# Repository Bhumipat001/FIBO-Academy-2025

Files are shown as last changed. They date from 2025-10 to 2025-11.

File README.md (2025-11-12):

# The Desktop Friend Robot (Companion Robot)

## Project CatLover
A robotic friend that follows and interacts with humans, designed with a cute and emotional personality.

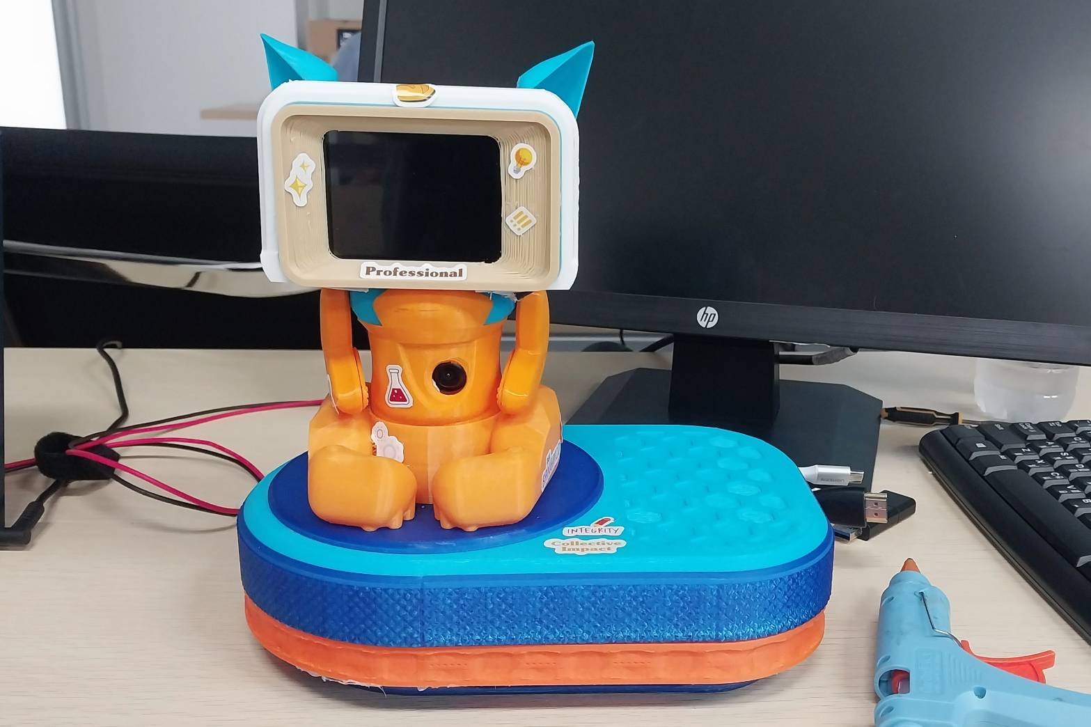
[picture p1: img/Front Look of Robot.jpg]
Front View of the Robot


This project is currently a prototype that simulates some of the features envisioned for the robot.

---

## What Does the Program Do?
The program is designed to **sense humans and interact with them based on specific conditions**.

### Devices Used
The project involves two main devices:
1. **ESP32 (WROOM)** - Handles low-level support and acts as a hub for sensors.
2. **Raspberry Pi (4 Model B)** - Provides high-level support for advanced features.

### ESP32 Features
- **Sensors**:
  - Capacitive Touch (built-in)
  - 24GHz mmWave Radar (via UART - Serial2)
- **Actuators**:
  - Vibrator Motor (PWM)
  - Light Strip (WS2812B)
  - Servo Motors

### Raspberry Pi Features
- **Image Processing**: Object detection
- **Display**: ILI9341V (via SPI)
- **Sound**: Audio output
- **Motion Expression**

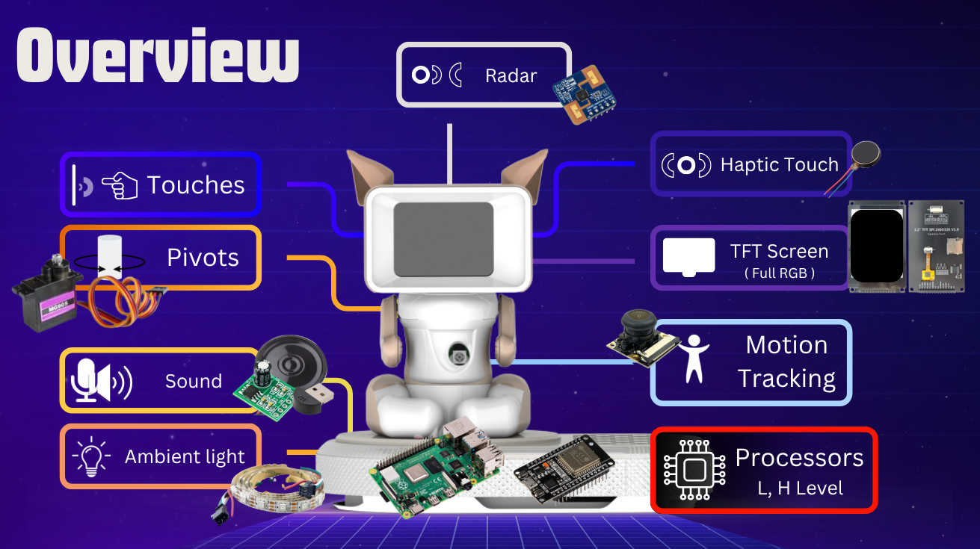
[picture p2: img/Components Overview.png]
Components of the Robot


---

## Components

### ESP32 Connections
| Device | Connection |
|---|---|
| Servo | PWM: 4, 5, 16, 17, 18, 19, 21, 22 |
| Touch (Wire/Metal Sheet)| GPIO: 12, 13, 14, 27, 32, 33 |
| Light Strip | NZR: 0, 23 |
| Radar | UART: Serial2 |
| Vibrator (Signal) | PWM: 2 |
| Raspberry Pi | UART: Serial0 |

### Raspberry Pi Connections
| Device | Connection |
|---|---|
| Pi Camera | SCI (Ribbon Cable) |
| Display | SPI: 8(CS), 9(MISO), 10(MOSI), 11(SCK), 24(RS), 25(RST) |
| ESP32 | UART: Serial |
| Speaker | Aux Jack |

---

## Design
The robot is designed to **mimic a cat-like appearance** with creative elements, including a CRT display head and a hybrid human-like look.

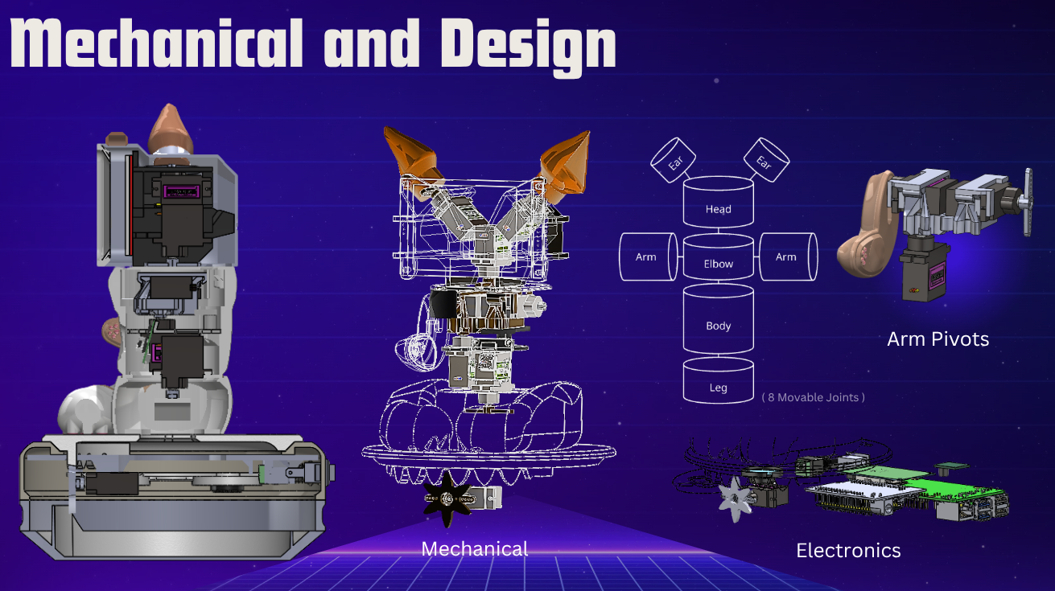
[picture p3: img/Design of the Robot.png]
Design of the Robot


### 3D Design (CAD)
- [STEP Assembly](https://github.com/Bhumipat001/FIBO-Academy-2025/tree/main/CAD/STEP)
- [STL Files](https://github.com/Bhumipat001/FIBO-Academy-2025/tree/main/CAD/STL)

**Note**: The design is optimized for **3D printing** (FDM printers).

---

## Materials
### Sensors
- `1` 24GHz mmWave Radar (Waveshare)
- `1` Pi Camera with Fish Eye Lens (130°)
- `A small amount` of thin metallic material (e.g., aluminum tape)

### Actuators
- `8` Servo Motors
- `2` Light Strips (WS2812B)
- `1` Vibrator Motor

### Compute Modules
- `1` ESP32 WROOM
- `1` Raspberry Pi 4 Model B

### Other Components
- `1` 3.2" TFT Screen
- `1` Speaker (10 mm or 17 mm) with Amplifier
- `Some` wires, power supply, switches, connectors, etc.

---

## Program Summary
The system uses a local **MQTT broker** (e.g., Mosquitto) for communication between the Raspberry Pi and ESP32 (via a middleware program).

### Simplified Algorithms
#### Raspberry Pi
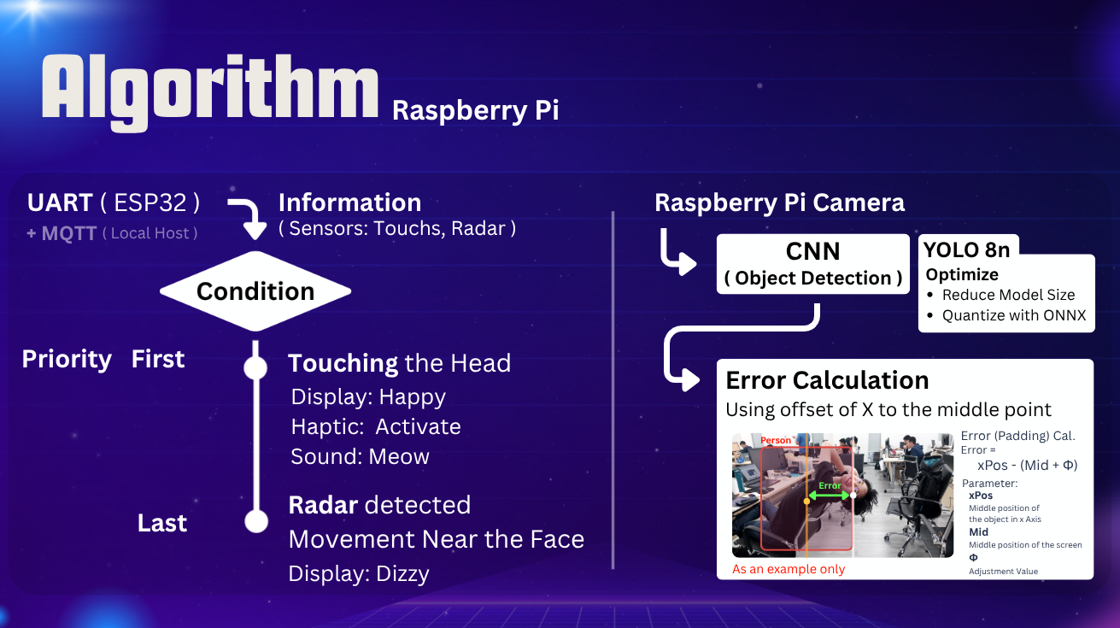
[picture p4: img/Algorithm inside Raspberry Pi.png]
Simplified Algorithm of Raspberry Pi


#### ESP32
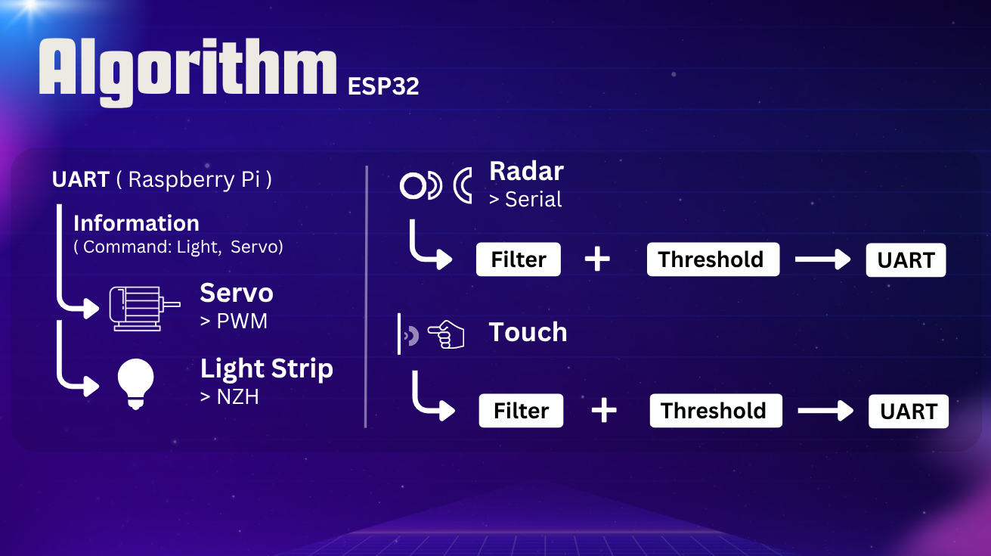
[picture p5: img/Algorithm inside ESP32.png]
Simplified Algorithm of ESP32


---

### Tracking Program
The repository includes an object detection model optimized from YOLOv8n. The program's goal is to move the focus object to the center of the screen.

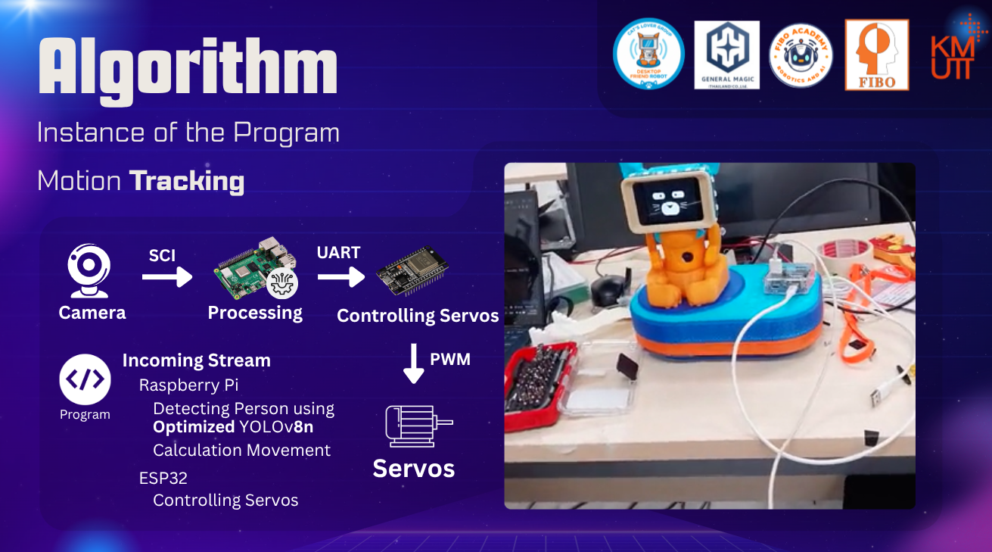
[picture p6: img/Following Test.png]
Algorithm of the Tracking Program


---

### Radar Program
This implementation tests the radar's ability to sense a hand in front of the robot's face without physical contact. The radar uses the Doppler effect to detect motion.

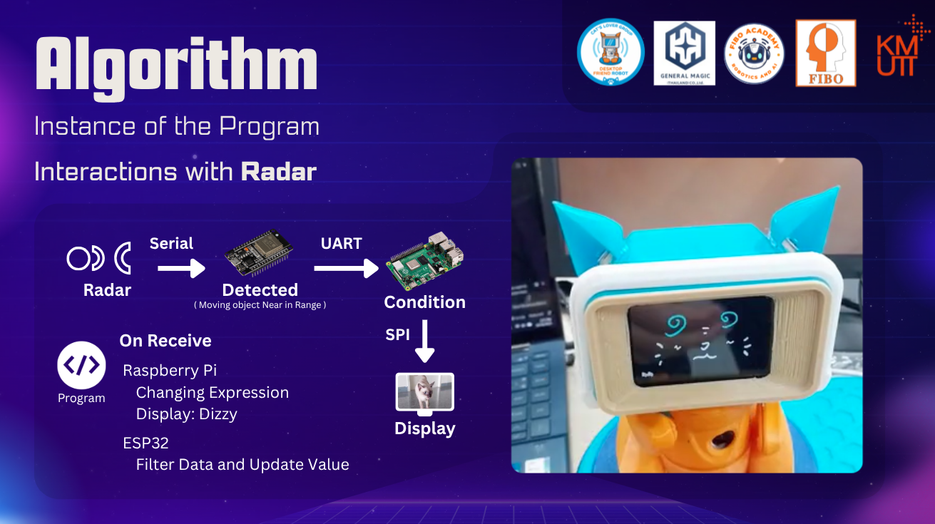
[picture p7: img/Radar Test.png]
Algorithm of the Radar Program


**Note**: 
- The algorithm can be improved in many ways.
- The radar is more effective at detecting moving objects but may produce noise if the sensor itself moves.

For more details, refer to the [presentation slides](https://github.com/Bhumipat001/FIBO-Academy-2025/blob/main/Present%20Slide.pdf).

---
## Setup
Follow these steps to set up the system. Note that this is a basic setup and may require adjustments.

### Raspberry Pi Setup
**Distro**: Raspberry Pi OS (default username: `pi`)

1. **Update and Install Dependencies**  
   - Update the system and install required libraries.  
   - Enable SPI and UART pins via `raspi-config`.

2. **Create a Python Virtual Environment**  
   ```bash
   cd ~
   python3 -m venv RobotEnv
   ```

3. **Install Python Libraries**  
   Activate the virtual environment and install the required libraries.

4. **Clone the Raspberry Pi Code**  
   ```bash
   cd ~
   git clone https://github.com/Bhumipat001/FIBO-Academy-2025.git
   mv FIBO-Academy-2025/Desktop\ Friend\ Robot/Raspberry\ Pi\ 4/ ~/RobotFriend
   rm -rf ~/FIBO-Academy-2025
   ```

5. **Create and Enable a Systemd Service Unit File**  
   Set up a service to run the program automatically on boot.

6. **Test and Run the Program**  
   Start the program and ensure everything is working as expected.

---

### ESP32 Setup
1. **Install Required Libraries**  
   Install the necessary libraries in your Arduino IDE or other development environment.

2. **Upload the Code**  
   Flash the ESP32 with the provided code.

3. **Test the Setup**  
   Verify the ESP32 is communicating correctly with the Raspberry Pi.

---

**Note**: For both setups, patience and testing are key. Good luck! Gooses and Cats bless you🙏

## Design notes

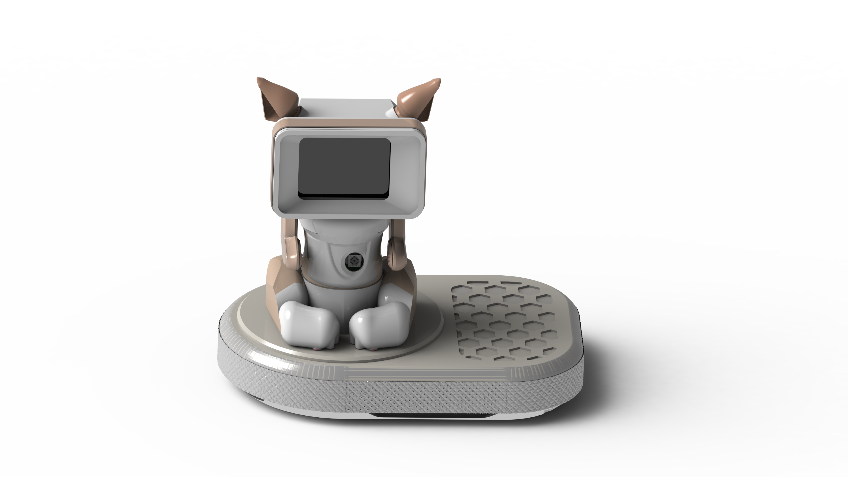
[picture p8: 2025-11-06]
CAD/Render/Assem TF View.png

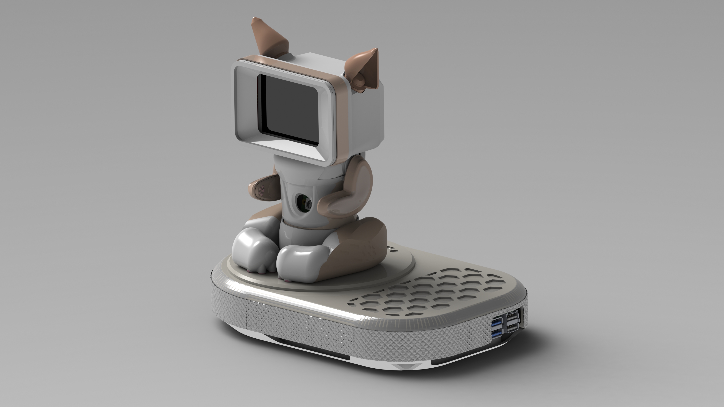
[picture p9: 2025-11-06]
CAD/Render/Assem RF View.JPG

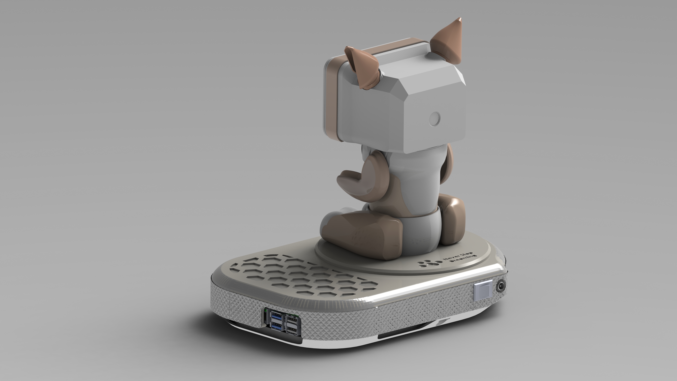
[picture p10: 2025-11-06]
CAD/Render/Assem RB View.JPG

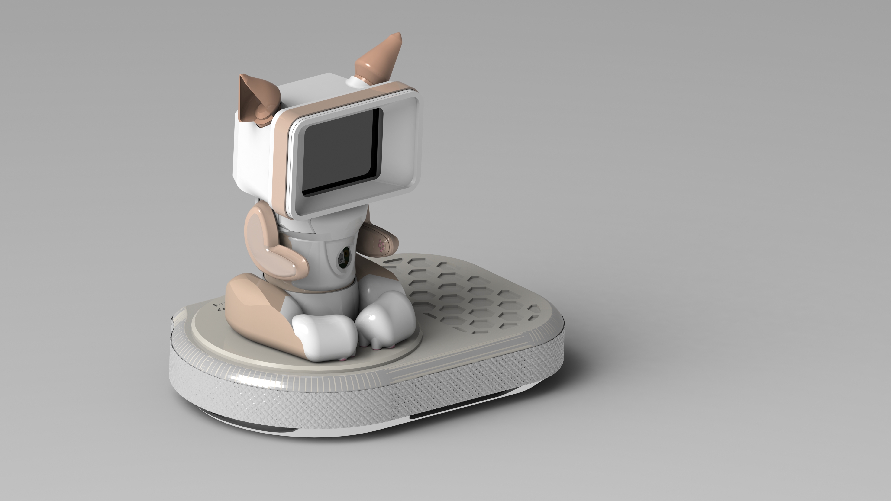
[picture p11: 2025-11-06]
CAD/Render/Assem ISO View.JPG

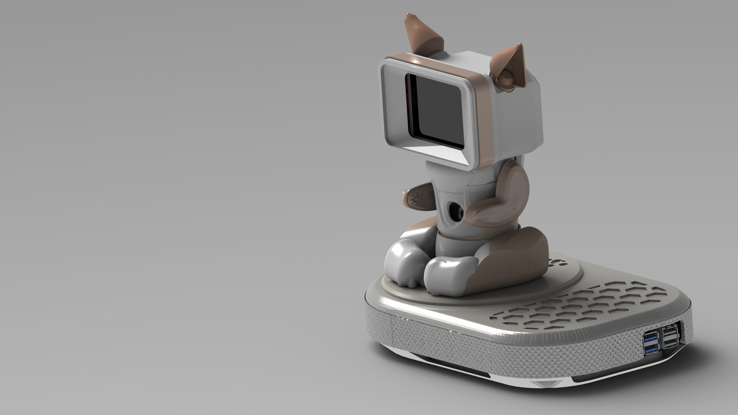
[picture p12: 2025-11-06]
CAD/Render/Assem RrF View.JPG

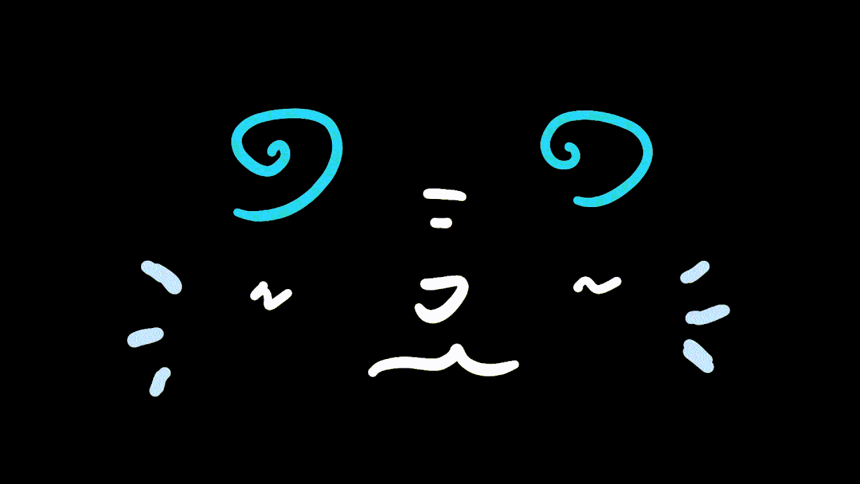
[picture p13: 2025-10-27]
Desktop Friend Robot/Raspberry Pi 4/screen/dizzy.gif

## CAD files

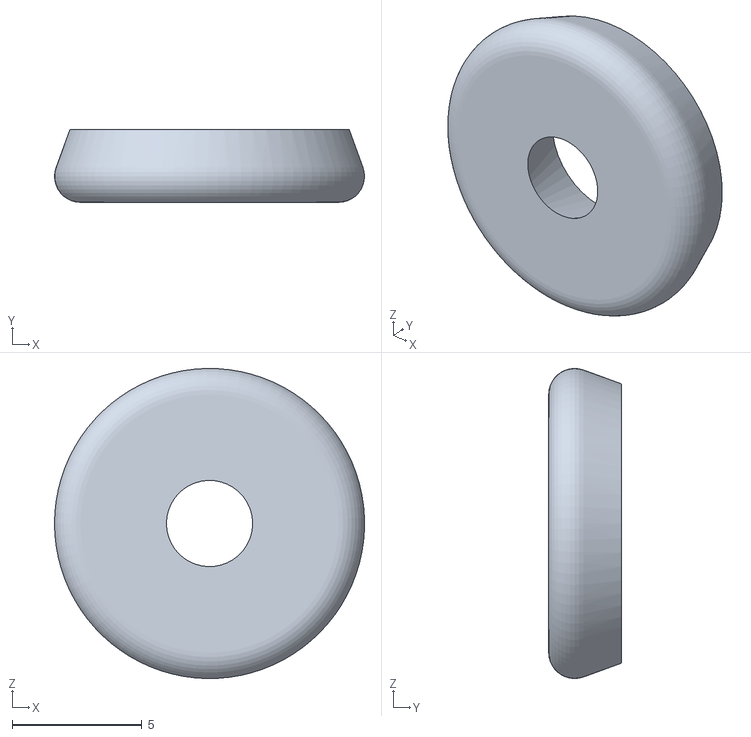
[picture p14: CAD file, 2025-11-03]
CAD/STL/Base and Leg/Base Connector Ring x2.STL
11.9 x 2.80 x 11.9

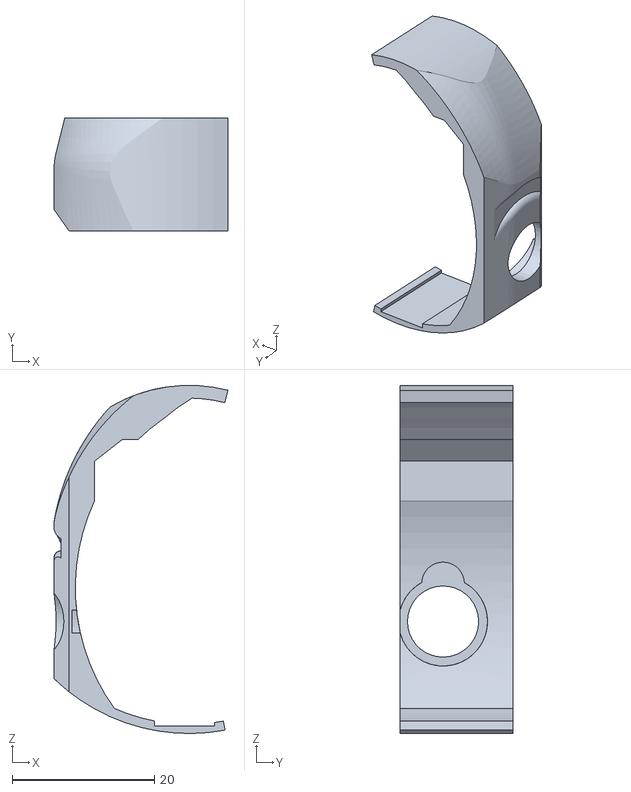
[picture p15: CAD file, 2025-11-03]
CAD/STL/Body/Body Right Cover.STL
24.5 x 15.8 x 48.9

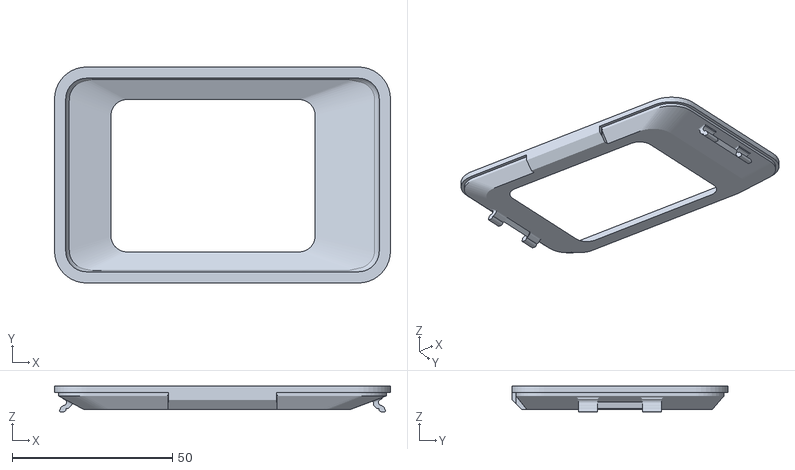
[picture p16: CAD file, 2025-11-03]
CAD/STL/Head/Head Front Cover.STL
105.0 x 67.5 x 8.00

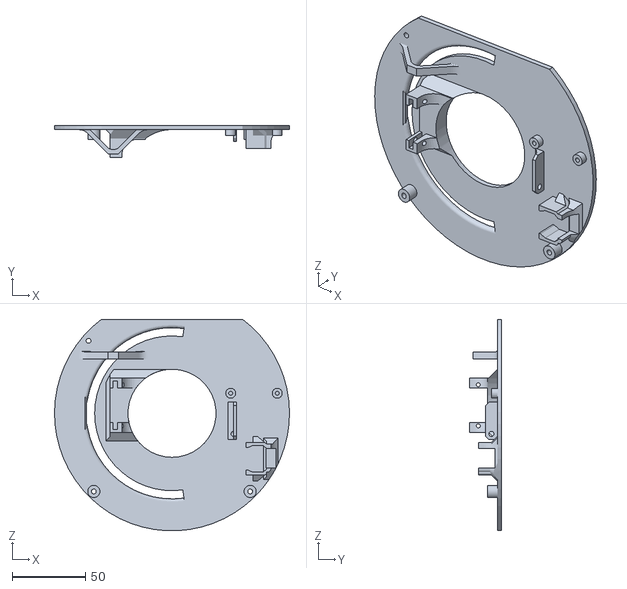
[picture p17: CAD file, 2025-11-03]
CAD/STL/Base and Leg/Base L1.STL
160.1 x 22.1 x 143.9

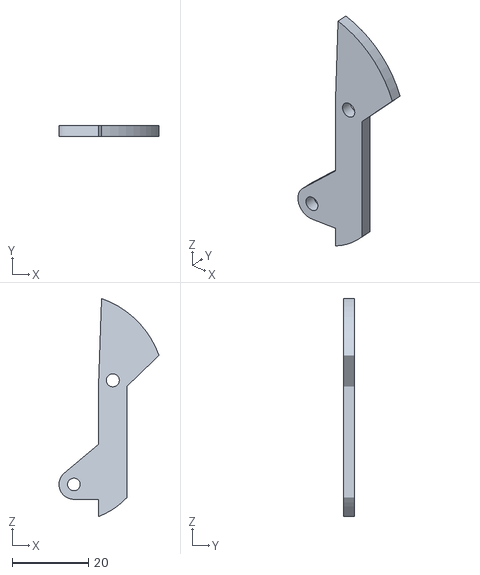
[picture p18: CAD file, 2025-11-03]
CAD/STL/Body/Body L2.STL
26.2 x 2.80 x 57.1

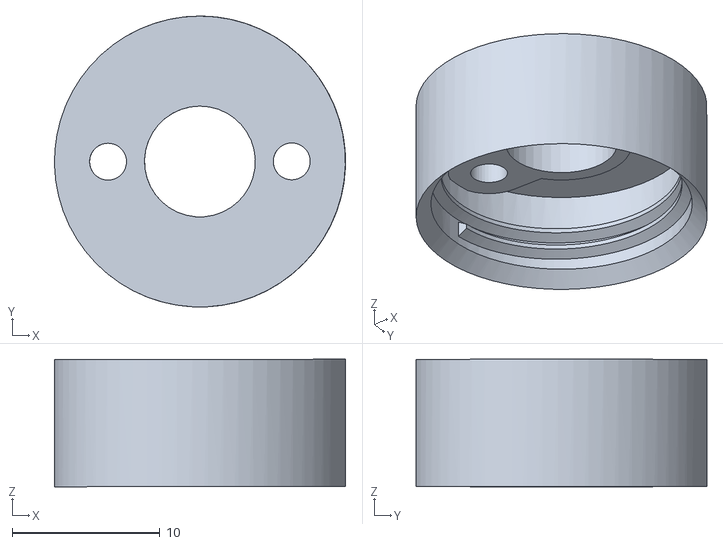
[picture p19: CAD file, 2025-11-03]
CAD/STL/Head/Servo Ear Right Connector.STL
19.7 x 19.7 x 8.63

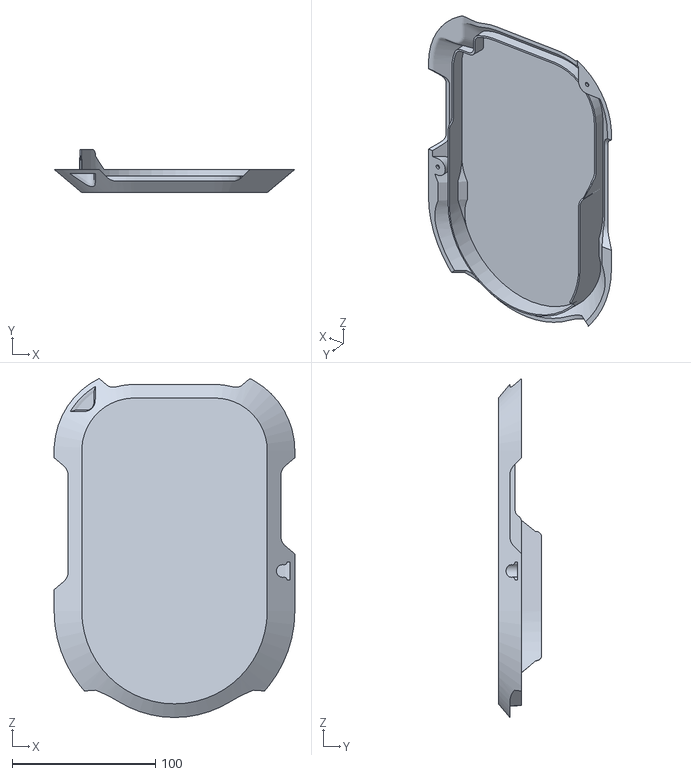
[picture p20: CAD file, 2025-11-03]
CAD/STL/Base and Leg/Base Cover.STL
168.0 x 30.2 x 236.5

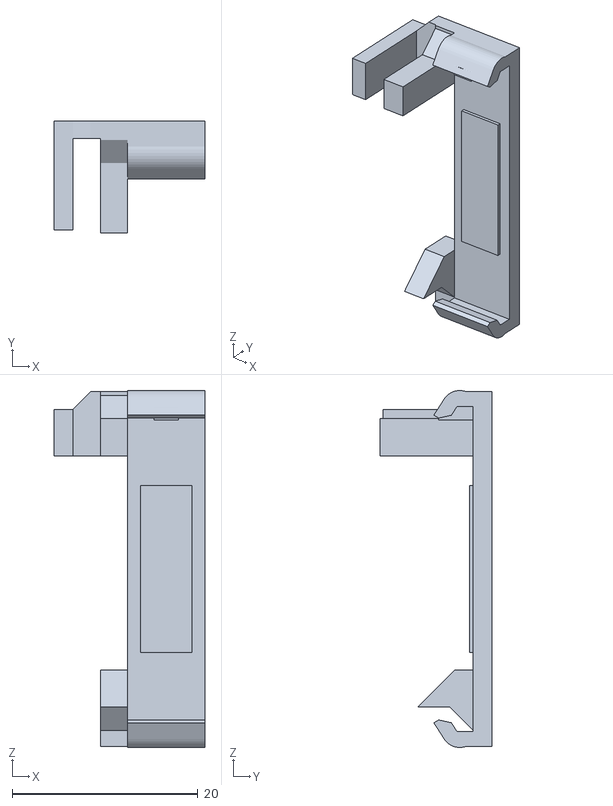
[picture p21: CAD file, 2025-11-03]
CAD/STL/Body/Gear Locker Right.STL
16.2 x 12.0 x 38.4

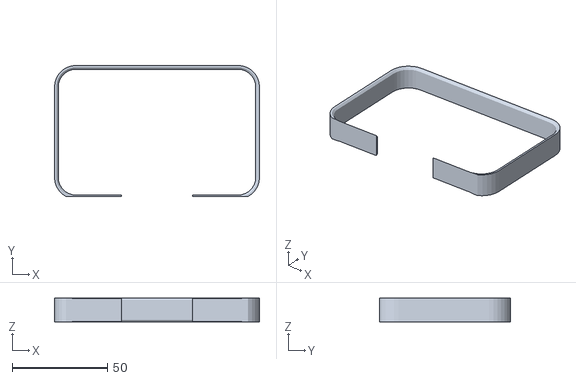
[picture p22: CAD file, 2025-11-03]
CAD/STL/Head/Head noDiff.STL
107.5 x 68.8 x 12.4

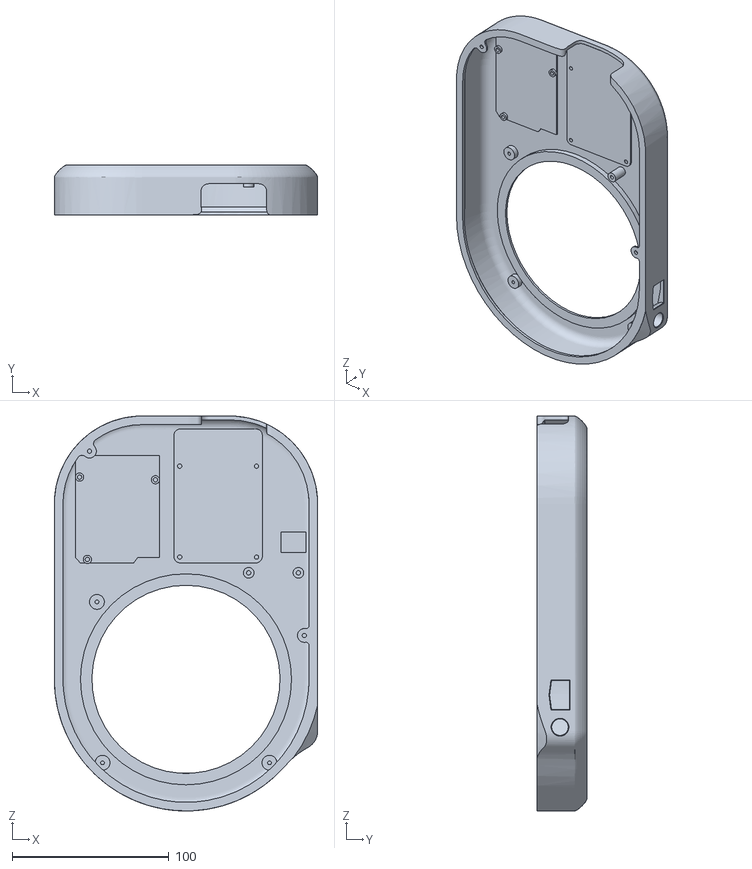
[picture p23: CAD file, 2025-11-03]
CAD/STL/Base and Leg/Base.STL
168.0 x 32.0 x 252.0

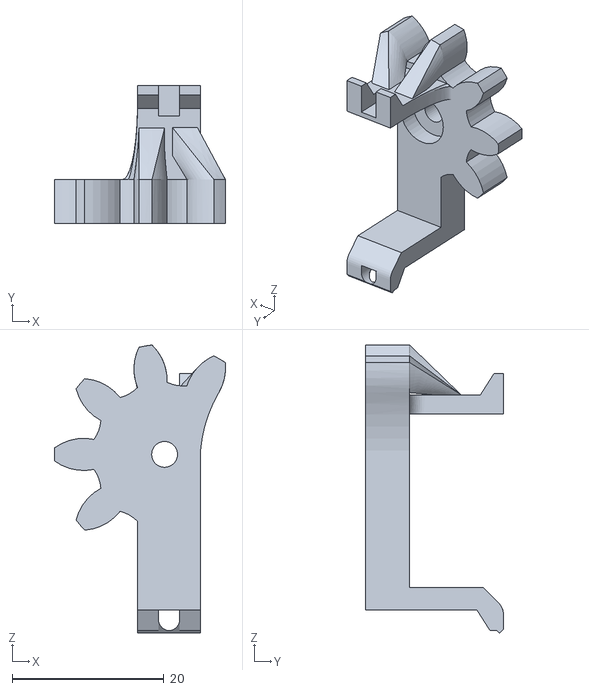
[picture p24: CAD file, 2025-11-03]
CAD/STL/Body/Gear Left.STL
22.5 x 18.2 x 37.9

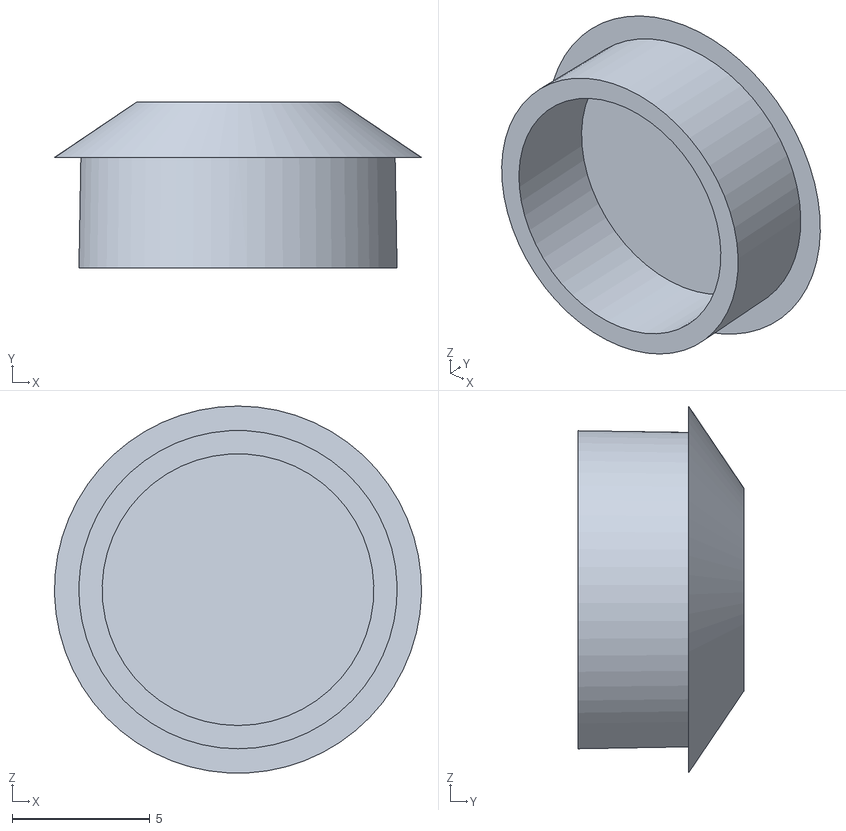
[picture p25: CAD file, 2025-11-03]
CAD/STL/Head/Servo Ears Cover x2.STL
13.3 x 6.00 x 13.3

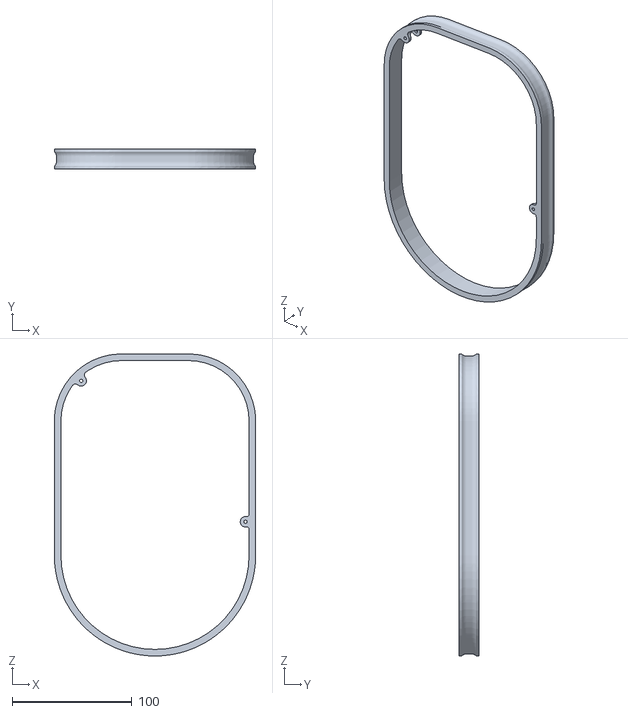
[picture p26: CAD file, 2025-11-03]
CAD/STL/Base and Leg/Base Extender.STL
168.0 x 17.0 x 252.0

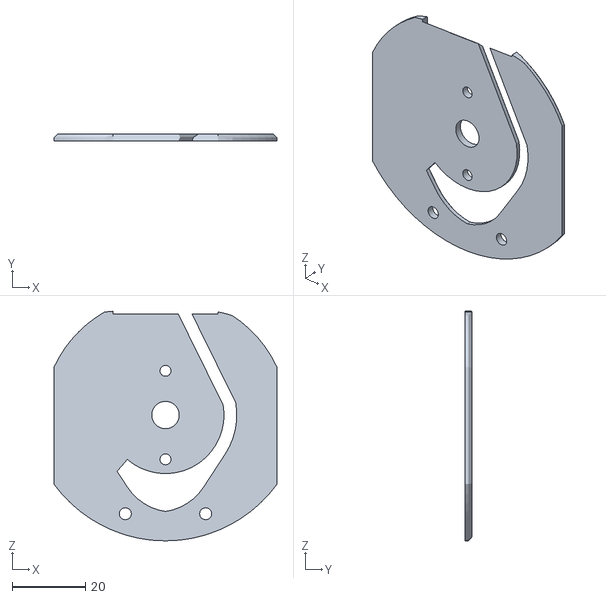
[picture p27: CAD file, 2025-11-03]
CAD/STL/Body/Body L3.STL
61.0 x 1.90 x 62.8

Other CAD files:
CAD/STL/Head/Head Diff.STL
CAD/STL/Base and Leg/Speaker Holder.STL
CAD/STL/Body/Body Left Cover.STL
CAD/STL/Head/Servo Ear Left Connector.STL
CAD/STL/Base and Leg/Base Connector Gear.STL
CAD/STL/Base and Leg/Base Connector.STL
CAD/STL/Base and Leg/Leg.STL
CAD/STL/Body/Body L1.STL
CAD/STL/Body/Body.STL
CAD/STL/Body/Gear Locker Left.STL
CAD/STL/Body/Gear Right.STL
CAD/STL/Head/Head Shell.STL
CAD/STL/Head/Head Structure.STL
CAD/STL/Head/Left Ear.STL
CAD/STL/Head/Right Ear.STL

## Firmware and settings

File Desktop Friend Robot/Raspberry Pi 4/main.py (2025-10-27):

import threading
import time
import paho.mqtt.client as mqtt

MQTT_BROKER = "localhost"
MQTT_PORT = 1883

TOPIC_TOUCH = "/touch"
TOPIC_HAPTIC = "/haptic"
TOPIC_SERVO = "/servo"
TOPIC_SCREEN = "/screen"
TOPIC_RADAR = "/radar"
TOPIC_SOUND = "/sound"
TOPIC_SLEEP = "/sleep"

class HeadState:
    def __init__(self):
        self.lock = threading.Lock()
        self.head_active_now = False
        self.active = False
        self.off_timer = None
        self.radar_active = False
        self.radar_off_timer = None
        self.radar_blocked = False
        self.radar_block_timer = None
        self.sleeping = False
        self.inactivity_timer = None
        self.radar_subscribed = True

def parse_touch_payload(payload: str):
    try:
        s = payload.strip()
        if s.lower().startswith("touch:"):
            s = s.split(":", 1)[1].strip()
        parts = [p.strip() for p in s.split(",") if p.strip()]
        result = {}
        for part in parts:
            if "=" in part:
                k, v = part.split("=", 1)
                result[k.strip()] = int(v.strip())
        return result
    except Exception:
        return {}

def on_connect(client, userdata, flags, reasonCode, properties=None):
    try:
        code = int(reasonCode)
    except Exception:
        code = reasonCode
    print(f"Connected to MQTT broker with result code: {code}")
    client.subscribe(TOPIC_TOUCH)
    print(f"Subscribed to topic: {TOPIC_TOUCH}")
    client.subscribe(TOPIC_SLEEP)
    print(f"Subscribed to topic: {TOPIC_SLEEP}")
    client.subscribe(TOPIC_RADAR)
    print(f"Subscribed to topic: {TOPIC_RADAR}")
    userdata.radar_subscribed = True

def on_message(client, userdata: HeadState, msg):
    if msg.topic == TOPIC_TOUCH:
        handle_touch(client, userdata, msg)
    elif msg.topic == TOPIC_RADAR:
        handle_radar(client, userdata, msg)
    elif msg.topic == TOPIC_SLEEP:
        handle_sleep(client, userdata, msg)

def wake_if_sleeping(client, st: HeadState):
    if st.sleeping:
        client.publish(TOPIC_SLEEP, "0")
        print("Waking from sleep -> sleep=0")
        st.sleeping = False
        if not st.radar_subscribed:
            client.subscribe(TOPIC_RADAR)
            st.radar_subscribed = True
            print(f"Subscribed to topic: {TOPIC_RADAR}")

def update_inactivity_timer(client, st: HeadState):
    idle = not st.head_active_now
    if idle:
        if st.inactivity_timer is None:
            def go_sleep():
                with st.lock:
                    if (not st.head_active_now) and (not st.sleeping):
                        client.publish(TOPIC_SLEEP, "1")
                        print("Inactivity 3m -> sleep=1")
                        st.sleeping = True
                        if st.radar_subscribed:
                            client.unsubscribe(TOPIC_RADAR)
                            st.radar_subscribed = False
                            print(f"Unsubscribed from topic: {TOPIC_RADAR}")
                    st.inactivity_timer = None
            st.inactivity_timer = threading.Timer(180.0, go_sleep)
            st.inactivity_timer.daemon = True
            st.inactivity_timer.start()
    else:
        if st.inactivity_timer:
            st.inactivity_timer.cancel()
            st.inactivity_timer = None

def handle_sleep(client, userdata: HeadState, msg):
    payload = msg.payload.decode("utf-8", errors="ignore").strip().lower()
    try:
        if payload.startswith("sleep:"):
            val = payload.split(":", 1)[1].strip()
        else:
            val = payload
        new_state = (val == "1")
    except Exception:
        return

    st = userdata
    with st.lock:
        prev = st.sleeping
        st.sleeping = new_state
        if new_state:
            if st.inactivity_timer:
                st.inactivity_timer.cancel()
                st.inactivity_timer = None
            if st.radar_subscribed:
                client.unsubscribe(TOPIC_RADAR)
                st.radar_subscribed = False
                print(f"Unsubscribed from topic: {TOPIC_RADAR}")
        else:
            if not st.radar_subscribed:
                client.subscribe(TOPIC_RADAR)
                st.radar_subscribed = True
                print(f"Subscribed to topic: {TOPIC_RADAR}")
            update_inactivity_timer(client, st)
        if new_state != prev:
            print(f"/sleep received -> sleeping={st.sleeping}")

def handle_touch(client, userdata: HeadState, msg):
    payload = msg.payload.decode("utf-8", errors="ignore").strip()
    values = parse_touch_payload(payload)
    L_HEAD = int(values.get("L_HEAD", 0))
    R_HEAD = int(values.get("R_HEAD", 0))
    head_now = (L_HEAD == 1) or (R_HEAD == 1)

    st = userdata
    with st.lock:
        st.head_active_now = head_now

        if head_now:
            wake_if_sleeping(client, st)

            if st.off_timer:
                st.off_timer.cancel()
                st.off_timer = None

            if not st.active:
                client.publish(TOPIC_HAPTIC, "1")
                client.publish(TOPIC_SERVO, "ear1")
                client.publish(TOPIC_SCREEN, "happy")
                client.publish(TOPIC_SOUND, "meow")
                st.active = True
                print("Head touch detected -> haptic=1, servo='ear1', screen='happy', sound='meow'")
            elif st.radar_active:
                client.publish(TOPIC_SCREEN, "happy")
                print("Touch overrides radar -> screen='happy'")
        else:
            if st.off_timer:
                st.off_timer.cancel()

            def do_off():
                with st.lock:
                    if not st.head_active_now and st.active:
                        client.publish(TOPIC_HAPTIC, "0")
                        client.publish(TOPIC_SERVO, "ear0")
                        client.publish(TOPIC_SCREEN, "normal")
                        print("Head released 3s -> haptic=0, servo='ear0', screen='normal'")
                        st.active = False
                        
                        st.radar_blocked = True
                        if st.radar_block_timer:
                            st.radar_block_timer.cancel()
                        
                        def unblock_radar():
                            with st.lock:
                                st.radar_blocked = False
                                st.radar_block_timer = None
                                if st.radar_active and not st.active:
                                    client.publish(TOPIC_SCREEN, "dizzy")
                                    print("Radar unblocked and still active -> screen='dizzy'")
                                else:
                                    print("Radar unblocked after touch cooldown")
                        
                        st.radar_block_timer = threading.Timer(3.0, unblock_radar)
                        st.radar_block_timer.daemon = True
                        st.radar_block_timer.start()
                    st.off_timer = None

            st.off_timer = threading.Timer(3.0, do_off)
            st.off_timer.daemon = True
            st.off_timer.start()

        update_inactivity_timer(client, st)

def handle_radar(client, userdata: HeadState, msg):
    payload = msg.payload.decode("utf-8", errors="ignore").strip()
    
    radar_state = 0
    try:
        if payload.lower().startswith("radar:"):
            radar_state = int(payload.split(":", 1)[1].strip())
        else:
            radar_state = int(payload)
    except Exception:
        return

    st = userdata
    with st.lock:
        if radar_state == 1:
            wake_if_sleeping(client, st)

            if st.radar_off_timer:
                st.radar_off_timer.cancel()
                st.radar_off_timer = None

            if not st.radar_active:
                st.radar_active = True
                if not st.active and not st.radar_blocked:
                    client.publish(TOPIC_SCREEN, "dizzy")
                    print("Radar detected -> screen='dizzy'")
                elif st.radar_blocked:
                    print("Radar detected but blocked (touch cooldown) -> no action")
                else:
                    print("Radar detected but touch active -> keeping screen='happy'")
        else:
            if st.radar_off_timer:
                st.radar_off_timer.cancel()

            def do_radar_off():
                with st.lock:
                    if st.radar_active:
                        st.radar_active = False
                        if not st.active:
                            client.publish(TOPIC_SCREEN, "normal")
                            print("Radar cleared 3s -> screen='normal'")
                        else:
                            print("Radar cleared but touch active -> keeping screen='happy'")
                    st.radar_off_timer = None

            st.radar_off_timer = threading.Timer(3.0, do_radar_off)
            st.radar_off_timer.daemon = True
            st.radar_off_timer.start()

def main():
    state = HeadState()

    client = mqtt.Client(
        protocol=mqtt.MQTTv5,
        callback_api_version=mqtt.CallbackAPIVersion.VERSION2,
        userdata=state,
    )
    client.on_connect = on_connect
    client.on_message = on_message

    client.connect(MQTT_BROKER, MQTT_PORT)
    client.loop_start()

    try:
        while True:
            time.sleep(1)
    except KeyboardInterrupt:
        pass
    finally:
        with state.lock:
            if state.off_timer:
                state.off_timer.cancel()
                state.off_timer = None
            if state.radar_off_timer:
                state.radar_off_timer.cancel()
                state.radar_off_timer = None
            if state.radar_block_timer:
                state.radar_block_timer.cancel()
                state.radar_block_timer = None
            if state.inactivity_timer:
                state.inactivity_timer.cancel()
                state.inactivity_timer = None
        client.loop_stop()
        client.disconnect()

if __name__ == "__main__":
    main()

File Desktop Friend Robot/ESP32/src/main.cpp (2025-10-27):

#include <Arduino.h>
#include <ESP32Servo.h>
#include <Adafruit_NeoPixel.h>
#include "servo.h"
#include "light.h"
#include "touch.h"
#include "radar.h"
#include "follow.h"
#include "haptic.h"

const unsigned long LOOP_MS = 25;
const int BOOT_PIN = 15;
unsigned long lastCheckTime = 0;
bool bootSequenceComplete = false;
unsigned long bootCommandTime = 0;

TaskHandle_t TaskTouch;
TaskHandle_t TaskServo;
TaskHandle_t TaskLight;
TaskHandle_t TaskRadar;

void taskLight(void *pvParameters) {
  while (true) {
    updateEffects();
    updateHaptic();
    vTaskDelay(pdMS_TO_TICKS(20));
  }
}

void taskServo(void *pvParameters) {
  while (true) {
    static int lastBootPinState = LOW;
    int bootPinState = digitalRead(BOOT_PIN);
    if (bootPinState == HIGH && lastBootPinState == LOW && !bootSequenceComplete) {
      Serial.println("Boot pin HIGH - triggering boot sequence");
      bootCommandTime = millis();
    }
    lastBootPinState = bootPinState;

    while (Serial.available() > 0) {
      String command = Serial.readStringUntil('\n');
      command.trim();

      if (command.startsWith("Servo: ")) {
        String pose = command.substring(7);
        Serial.print("Executing pose: ");
        Serial.println(pose);
        if (!executePose(pose.c_str())) {
          Serial.print("Unknown pose: ");
          Serial.println(pose);
        }
      } else if (command.startsWith("Light: ")) {
        handleSerialCommand(command.substring(7));
      } else if (command.startsWith("LightBase: ")) {
        handleBaseSerialCommand(command.substring(11));
      } else if (command.startsWith("Haptic: ")) {
        String arg = command.substring(8);
        arg.trim();
        if (arg == "1") {
          setHapticEnabled(true);
          Serial.println("Haptic enabled");
        } else {
          setHapticEnabled(false);
          Serial.println("Haptic disabled");
        }
      } else if (command.startsWith("Body: ")) {
        String arg = command.substring(6);
        parsePanCommand(arg);
      } else if (command.startsWith("Head: ")) {
        String arg = command.substring(6);
        parseHeadCommand(arg);
      }
    }

    if (!bootSequenceComplete && bootCommandTime != 0 && (millis() - bootCommandTime >= 1000)) {
      handleSerialCommand("Hex(B5B5B5) Brightness(100) Fade(0)");
      handleBaseSerialCommand("Hex(FFB126) Brightness(100) Fade(0)");
      vTaskDelay(pdMS_TO_TICKS(2000));
      executePose("stretch");
      bootSequenceComplete = true;
    } else if (!bootSequenceComplete && bootCommandTime == 0) {
      handleSerialCommand("off");
      handleBaseSerialCommand("off");
    }

    updateTracking();
    vTaskDelay(pdMS_TO_TICKS(LOOP_MS));
  }
}

void setup() {
  Serial.begin(115200);
  Serial.setTimeout(10);
  
  initRadar();
  initLight();
  initHaptic();

  initServos();
  initPan();
  pinMode(BOOT_PIN, INPUT_PULLDOWN);
  if (digitalRead(BOOT_PIN) == HIGH) {
    Serial.println("BOOT_PIN is HIGH at startup - scheduling boot sequence");
    bootCommandTime = millis();
  }

  xTaskCreatePinnedToCore(taskLight, "TaskLight", 4096, NULL, 1, &TaskLight, 0);
  delay(1000);
  calibrateAllSensors();

  xTaskCreatePinnedToCore(taskTouch, "TaskTouch", 4096, NULL, 1, &TaskTouch, 0);
  xTaskCreatePinnedToCore(taskRadar, "TaskRadar", 4096, NULL, 1, &TaskRadar, 0);
  xTaskCreatePinnedToCore(taskServo, "TaskServo", 4096, NULL, 1, &TaskServo, 1);
}

void loop() {
}

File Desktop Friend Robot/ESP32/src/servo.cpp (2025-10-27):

#include <ESP32Servo.h>
#include <Arduino.h>
#include <string.h>
#include "servo.h"

// static Servo Base;
static Servo Body;
static Servo ArmBase;
static Servo R_Arm;
static Servo L_Arm;
static Servo Head;
static Servo R_Ear;
static Servo L_Ear;

static inline int clampAngle(int angle, int minA, int maxA) {
  if (angle < minA) return minA;
  if (angle > maxA) return maxA;
  return angle;
}

static inline void writeSafe(Servo &srv, int angle, int minA, int maxA) {
  srv.write(clampAngle(angle, minA, maxA));
}

#define servo(srv, angle) writeSafe(srv, angle, srv##_MIN, srv##_MAX)

void initServos() {
  // Base.attach(Base_PIN);
  Body.attach(Body_PIN);
  ArmBase.attach(ArmBase_PIN);
  R_Arm.attach(R_Arm_PIN);
  L_Arm.attach(L_Arm_PIN);
  Head.attach(Head_PIN);
  R_Ear.attach(R_Ear_PIN);
  L_Ear.attach(L_Ear_PIN);
}

void detachAllServos() {
  delay(1000);
  Body.detach();
  ArmBase.detach();
  R_Arm.detach();
  L_Arm.detach();
  Head.detach();
  R_Ear.detach();
  L_Ear.detach();
}

void attachAllServos() {
  Body.attach(Body_PIN);
  ArmBase.attach(ArmBase_PIN);
  R_Arm.attach(R_Arm_PIN);
  L_Arm.attach(L_Arm_PIN);
  Head.attach(Head_PIN);
  R_Ear.attach(R_Ear_PIN);
  L_Ear.attach(L_Ear_PIN);
}

void setBodyAngle(int angle) {
  servo(Body, angle);
}

void setHeadAngle(int angle) {
  servo(Head, angle);
}

typedef void (*PoseFunction)();

struct PoseEntry {
  const char* name;
  PoseFunction function;
};

#define ALL_POSES(P) \
  P(stretch) \
  P(ear) \
  P(clap) \
  P(no) \
  P(wave) \
  P(ear0) \
  P(ear1)

#define DECLARE_POSE(name) static void name();
#define REGISTER_POSE(name) {#name, name},

ALL_POSES(DECLARE_POSE)

static const PoseEntry poses[] = {
  ALL_POSES(REGISTER_POSE)
};

static const int numPoses = sizeof(poses) / sizeof(poses[0]);

static void stretch() {
  attachAllServos();
  // servo(Base, 30);
  servo(Body, 85);
  servo(ArmBase, 75);
  //servo(R_Arm, 70);
  //servo(L_Arm, 110);
  servo(Head, 100);
  servo(R_Ear, 130);
  servo(L_Ear, 50);
  delay(2000);
  //servo(ArmBase, 115);
  servo(R_Arm, 10);
  servo(L_Arm, 170);
  servo(R_Ear, 90);
  servo(L_Ear, 90);
  detachAllServos();
}

static void ear() {
  attachAllServos();
  servo(R_Ear, 130);
  servo(L_Ear, 50);
  delay(100);
  servo(R_Ear, 90);
  servo(L_Ear, 90);
  detachAllServos();
}

static void ear0() {
  attachAllServos();
  servo(R_Ear, 90);
  servo(L_Ear, 90);
  delay(300);
  detachAllServos();
}

static void ear1() {
  attachAllServos();
  servo(R_Ear, 130);
  servo(L_Ear, 50);
  delay(300);
  detachAllServos();
}

static void clap() {
  attachAllServos();
  servo(ArmBase, 90);
  servo(R_Arm, 90);
  servo(L_Arm, 90);
  delay(100);
  servo(ArmBase, 110);
  delay(100);
  servo(ArmBase, 75);
  delay(100);
  servo(ArmBase, 110);
  delay(100);
  servo(ArmBase, 75);
  delay(100);
  servo(ArmBase, 110);
  delay(100);
  servo(ArmBase, 90);
  servo(R_Arm, 10);
  servo(L_Arm, 170);
  detachAllServos();
}

static void no(){
  attachAllServos();
  servo(Head, 100);
  servo(Head, 80);
  delay(200);
  servo(Head, 120);
  delay(200);
  servo(Head, 80);
  delay(200);
  servo(Head, 120);
  delay(200);
  servo(Head, 80);
  delay(200);
  servo(Head, 120);
  servo(Head, 100);
  detachAllServos();
}

static void wave(){
  attachAllServos();
  servo(ArmBase, 90);
  servo(R_Arm, 90);
  delay(200);
  servo(R_Arm, 60);
  delay(100);
  servo(R_Arm, 90);
  delay(100);
  servo(R_Arm, 60);
  delay(100);
  servo(R_Arm, 90);
  delay(100);
  servo(R_Arm, 60);
  delay(100);
  servo(ArmBase, 90);
  servo(R_Arm, 10);
  detachAllServos();
}

bool executePose(const char* poseName) {
  for (int i = 0; i < numPoses; i++) {
    if (strcmp(poses[i].name, poseName) == 0) {
      poses[i].function();
      return true;
    }
  }
  return false;
}

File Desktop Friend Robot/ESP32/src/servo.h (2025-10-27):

#ifndef POSE_H
#define POSE_H
#include <Arduino.h>

constexpr int Base_MIN = 0;
constexpr int Base_MAX = 180;
constexpr int Body_MIN = 40;
constexpr int Body_MAX = 150;
constexpr int ArmBase_MIN = 75;
constexpr int ArmBase_MAX = 115;
constexpr int R_Arm_MIN = 10;
constexpr int R_Arm_MAX = 70;
constexpr int L_Arm_MIN = 110;
constexpr int L_Arm_MAX = 170;
constexpr int Head_MIN = 70;
constexpr int Head_MAX = 130;
constexpr int R_Ear_MIN = 90;
constexpr int R_Ear_MAX = 130;
constexpr int L_Ear_MIN = 50;
constexpr int L_Ear_MAX = 90;

constexpr int Base_PIN = 4;
constexpr int Body_PIN = 16;
constexpr int ArmBase_PIN = 17;
constexpr int R_Arm_PIN = 5;
constexpr int L_Arm_PIN = 18;
constexpr int Head_PIN = 19;
constexpr int R_Ear_PIN = 21;
constexpr int L_Ear_PIN = 22;

void initServos();
void detachAllServos();
void attachAllServos();
void setBodyAngle(int angle);
void setHeadAngle(int angle);

bool executePose(const char* poseName);

#endif

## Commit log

2025-11-03 Added CAD Files
    [Base Connector Gear.STL, Base Connector Ring x2.STL, Base Connector.STL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]
2025-11-05 Update README.md
    Making it more readable. 🤏
